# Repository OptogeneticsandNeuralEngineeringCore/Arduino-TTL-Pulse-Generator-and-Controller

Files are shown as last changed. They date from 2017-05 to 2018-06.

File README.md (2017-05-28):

# Arduino-TTL-Pulse-Generator-and-Controller

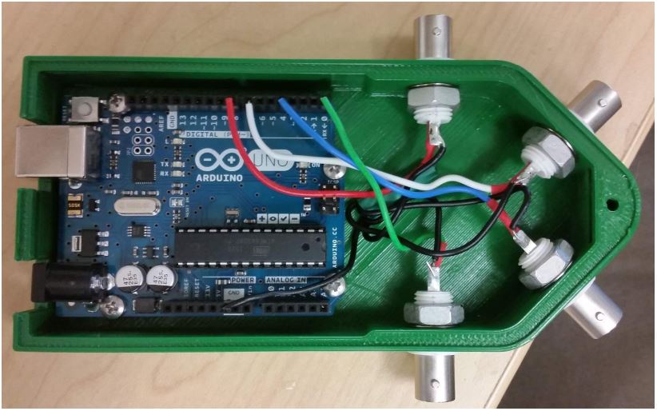
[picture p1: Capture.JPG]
Capture


Design and Control your experiments with a TTL Generator and Controller

An inexpensive Arduino controlled, four channel, simultaneous TTL pulse generator and controller with BNC connectors and optional 3D printed housing is detailed. TTL pulse modulation requires programing in the Arduino language, but 2 examples are given such **that no prior programing experience** is necessary. The first example shows how to set up four independent TTL outputs. The second example expands on this and allows for input into the generator for a closed loop system, controlled by TTL.

### Files

| File | Description | File Type  |
| --- | --- | --- |
| [Arduino Simple 4 Channel TTL Pulse Generator.pdf](https://github.com/OptogeneticsandNeuralEngineeringCore/Arduino-TTL-Pulse-Generator-and-Controller/raw/master/Arduino%20Simple%204%20Channel%20TTL%20Pulse%20Generato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) | The Main File for design and fabrication | pdf |
| Arduino simple 4 channel ttl top.ipt | Design file for enclosure top | ipt |
| Arduino simple 4 channel ttl top.stl | Printable file for enclosure top | stl |
| Arduino simple 4 channel ttl bottom.ipt | Design file for enclosure bottom | ipt |
| Arduino simple 4 channel ttl bottom.stl | Printable file for enclosure bottom | stl |
| Arduino_Simple_TTL.ino | Arduino file for TTL Generation | ino |
| Arduino_Simple_Closed_Loop.ino | Arduino file for TTL Control (TTL's triggered on input (button or IR Breakbeam) |ino |
| Screenshots of Downloading and Programing the Arduino.ppt | Help in downloading and Programing with Arduino | ppt |
| --- | --- | --- |
| --- | --- | --- |
| Arduino Simple 8 Channel MEGA TTL Pulse Generator.pdf | If more inputs/outputs are required, try the 8 channel system | .pdf |
| Arduino simple 8 channel ttl top.ipt | Design file for enclosure top | ipt |
| Arduino simple 8 channel ttl top.stl | Printable file for enclosure top | stl |
| Arduino simple 8 channel ttl bottom.ipt | Design file for enclosure bottom | ipt |
| Arduino simple 8 channel ttl bottom.stl | Printable file for enclosure bottom |stl |
| Arduino_Simple_Closed_Loop_Mega.ino | Arduino code for 8 channel system | ino |

### Introduction
Research labs often conduct experiments that require precise timing characteristics, synchronized across several signals. Pulse Width Modulation (PWM) is a digital on/off signal that carries information in the relative timing characteristics of the signal. Transistor Transistor Logic (TTL) is a form of PWM where the on state is 5 VDC and the off state is at 0 VDC. TTL is frequently employed to precisely control lab equipment such as lasers. Generation of the TTL signal often comes from expensive lab equipment and is carried through BNC cables from the generator to the equipment. The TTL signal is simple, but must be precisely controlled for correct on/off state and timing considerations. More information on TTL can be found here. Modern microcontrollers can easily accomplish the signal generation of more expensive equipment, for most applications. Arduino is a simple, inexpensive microcontroller that natively outputs TTL signals. The intent of this paper is to outline a method to fabricate an inexpensive TTL signal generator and controller. 
Arduino outputs PWM digital signals. When the Arduino is powered correctly, this signal is conveniently at 5VDC, and is therefore TTL. Although the chosen board (the Arduino Uno R3) outputs six channels, only four are employed in this design for ease. If six signals are required, it would be easy to expand on this design. If more than 6 channels are required, it may be possible to connect several Arduinos together, but there may be some delay to consider.
This document will outline the equipment, fabrication, and software required. The equipment is intended to be inexpensive. A model for an optional housing for the Arduino and four BNC connections is offered and maybe 3D printed. Fabrication of the final assembly is simple but does require the use of a soldering iron. The software is free. The Arduino programing language is similar to C+, but it is intended that no previous programing is required to generate TTL signals with this set up. Two example programs are given that are intended to be explained in such a way that signal generation can be designed simply by modifying the code in key places. One example shows how to generate four simultaneous signals, each with a unique pulse pattern that is repeated Ad infinitum. The other example shows how to use this set up to control a closed loop experiment. The examples can also be used as an introduction to coding and covers if, for, and while statements.

### ONE Core acknowledgement 
Please acknowledge the ONE Core facility in your publications. An appropriate wording would be:

"Engineering support was provided by the Optogenetics and Neural Engineering Core at the University of Colorado Anschutz Medical Campus, funded in part by the National Institute for Neurological Disorders and Stroke of the National Institutes of Health under award number P30NS048154."

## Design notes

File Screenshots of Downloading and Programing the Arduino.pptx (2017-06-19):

## Downloading the Arduino programing software and running the programs

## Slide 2

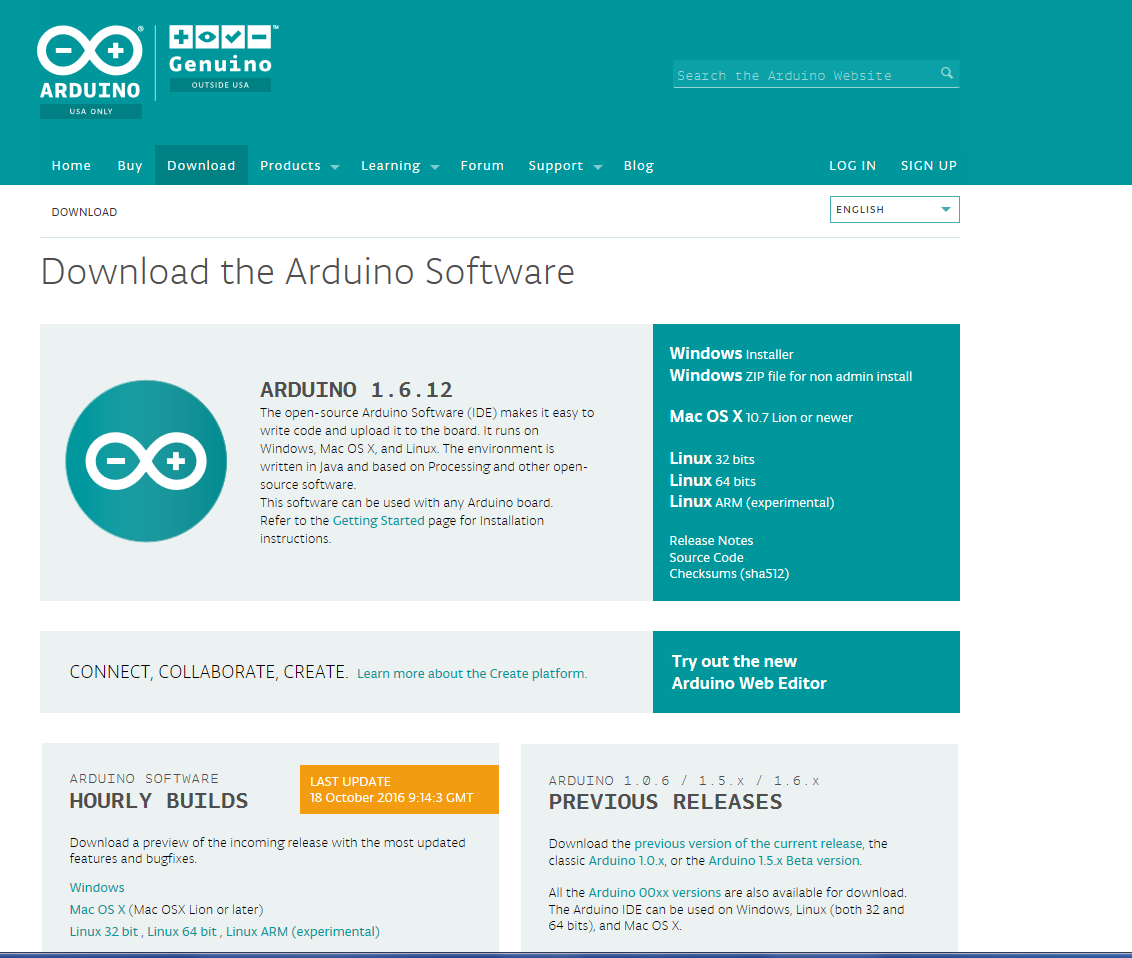
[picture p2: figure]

Installation

For windows click on windows. For mac click on mac. Follow the normal instruction for installation. Desire folder etc.

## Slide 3

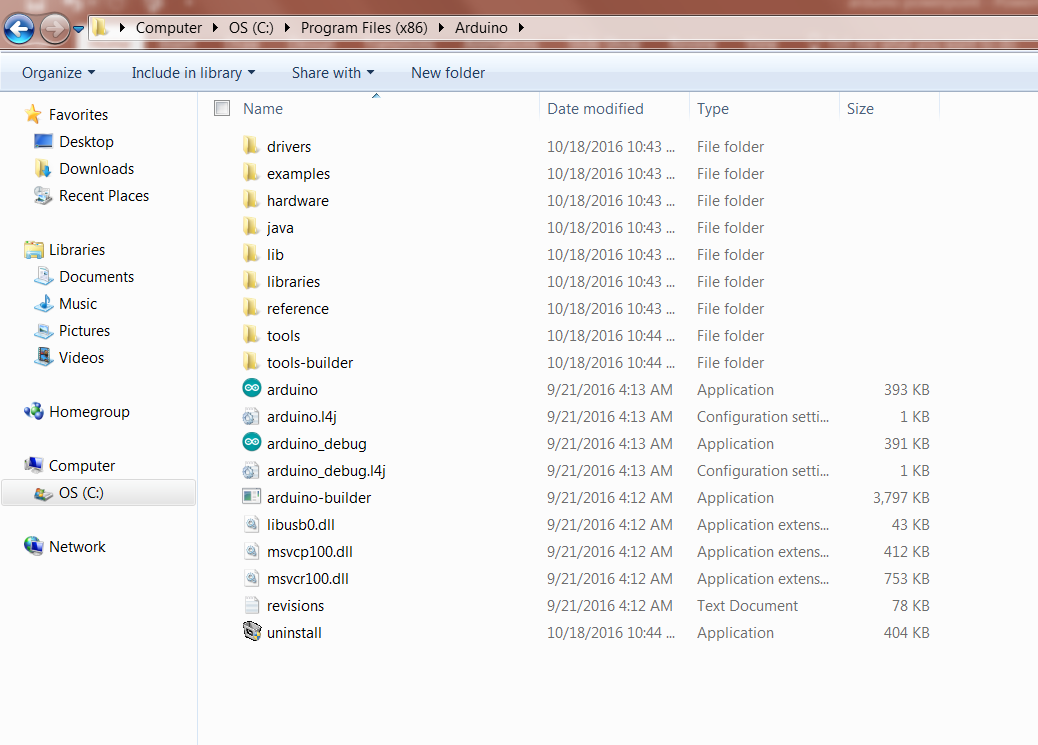
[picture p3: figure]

Go to the folder where you have installs Arduino. Click on Arduino to start the program

Installation

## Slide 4

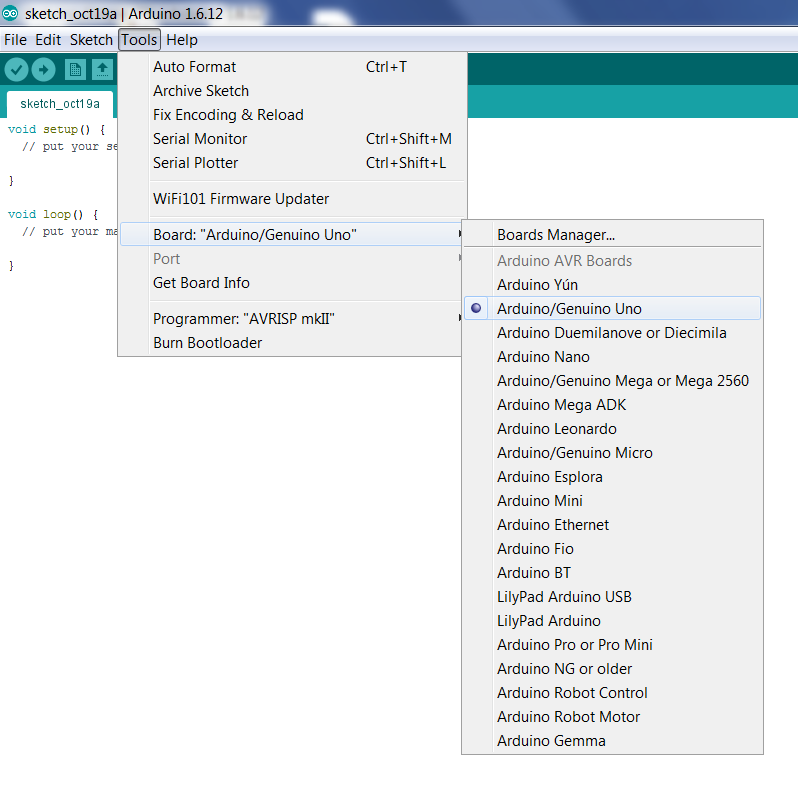
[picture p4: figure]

Connect

1. Connect the Arduino via the USB Cable.
2. In the Arduino window, select Tools > Boards > Arduino Genuiono Uno.

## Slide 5

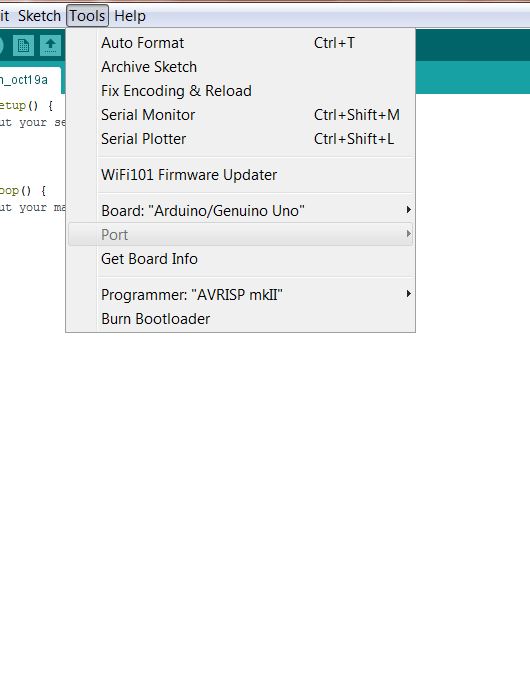
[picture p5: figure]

Connect

Then select Tools > Port > then select the board connected to the USB (typically COM4)

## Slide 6

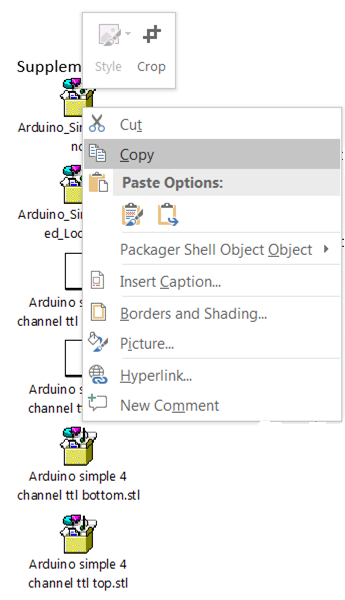
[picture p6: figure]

Obtaining files

Copy the sample files into a desire folder. Click on the file then right click and click on copy. Place the file in the desire folder. Repeat the steps for the rest of the files.

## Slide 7

Open Files

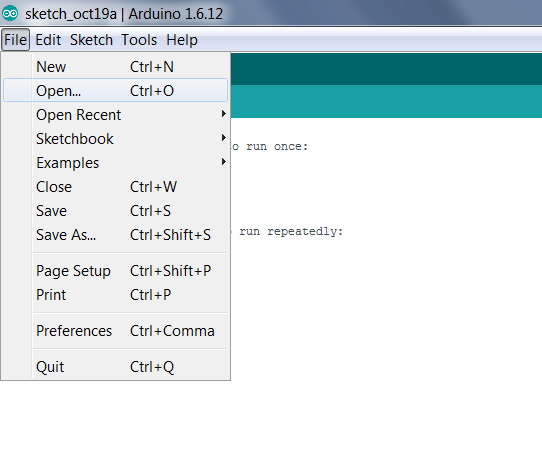
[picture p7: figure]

Open the desire program by clicking File >Arduino_Simple_Closed_loop
Or any program you want to run.

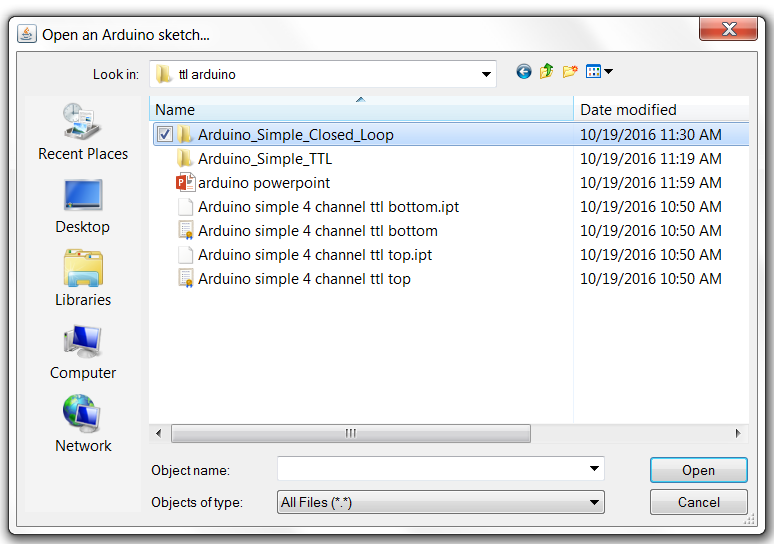
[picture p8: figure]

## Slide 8

Verify the program

Once the program is open click on the check mark

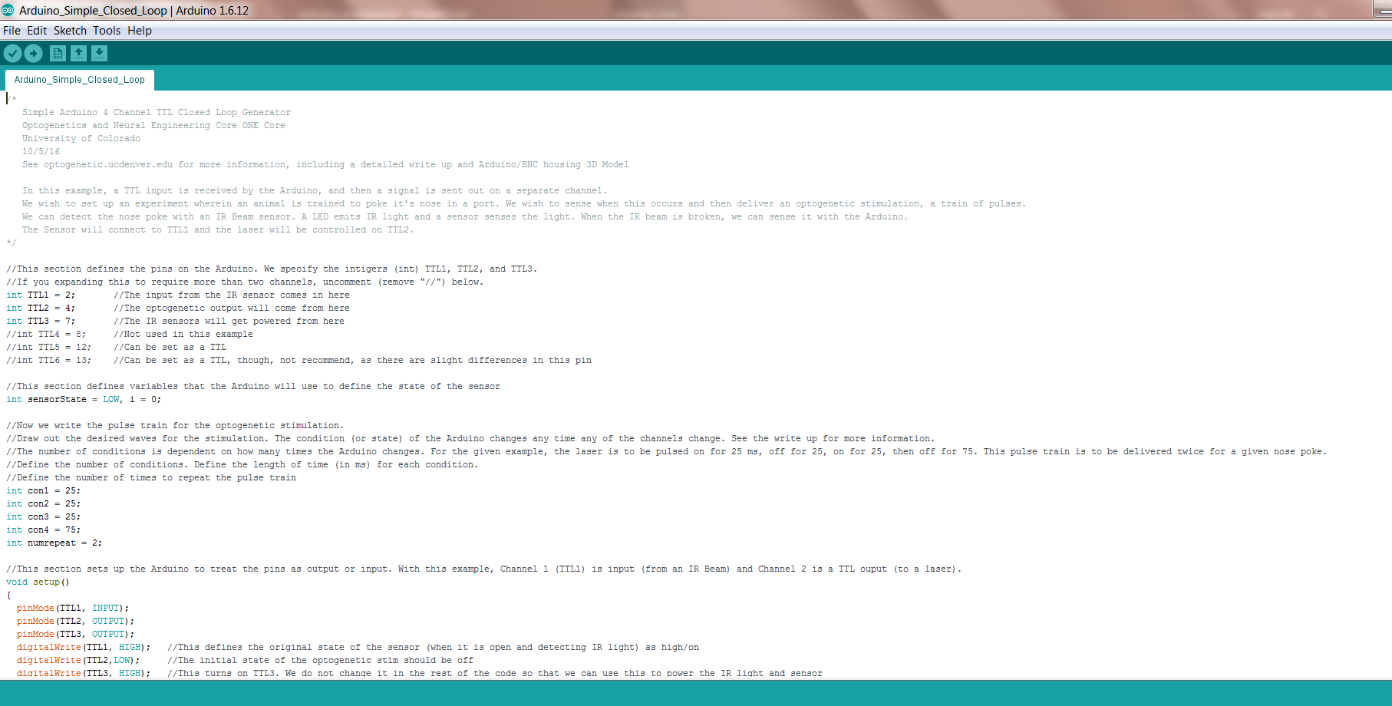
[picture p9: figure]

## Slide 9

Upload the program to Arduino

Click on the arrow to run the program

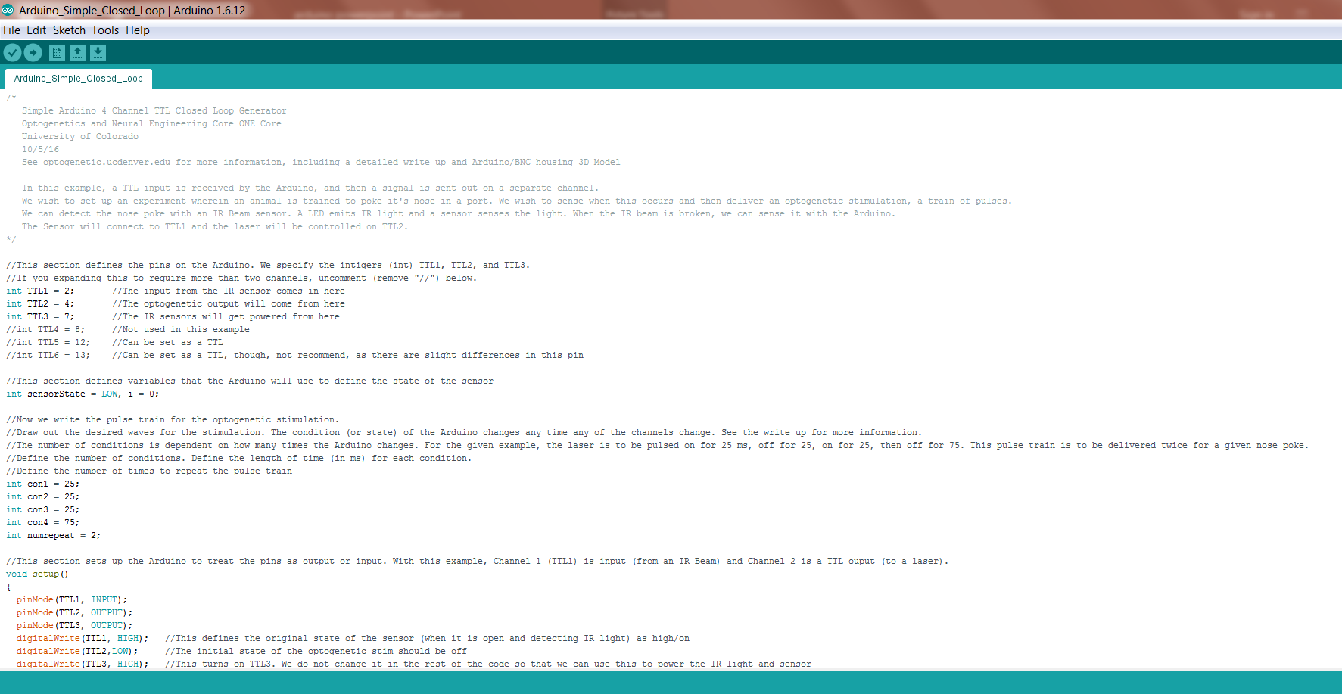
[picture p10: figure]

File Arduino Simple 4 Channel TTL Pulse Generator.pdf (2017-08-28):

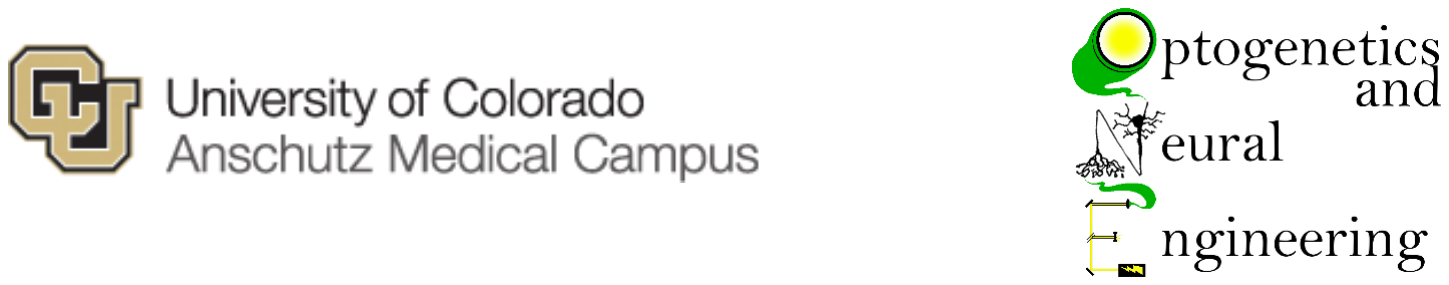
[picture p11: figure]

Arduino Simple 4 Channel TTL Pulse Generator and Controller

Developed and described by Andrew Scallon Optogenetics and Neural Engineering Core Abigail Person and Gidon Felsen, Directors Department of Physiology and Biophysics School of Medicine, University of Colorado

Introduction
Research labs often conduct experiments that require precise timing characteristics, synchronized across several signals. Pulse Width Modulation (PWM) is a digital on/off signal that carries information in the relative timing characteristics of the signal. Transistor Transistor Logic (TTL) is a form of PWM where the on state is 5 VDC and the off state is at 0 VDC. TTL is frequently employed to precisely control lab equipment such as lasers. Generation of the TTL signal often comes from expensive lab equipment and is carried through BNC cables from the generator to the equipment. The TTL signal is simple, but must be precisely controlled for correct on/off state and timing considerations. More information on TTL can be found here. (https://learn.sparkfun.com/tutorials/logic-levels) Modern microcontrollers can easily accomplish the signal generation of more expensive equipment, for most applications. Arduino is a simple, inexpensive microcontroller that natively outputs TTL signals. The intent of this paper is to outline a method to fabricate an inexpensive TTL signal generator and controller.
Arduino outputs PWM digital signals. When the Arduino is powered correctly, this signal is conveniently at 5VDC, and is therefore TTL. Although the chosen board (the Arduino Uno R3) outputs six channels, only four are employed in this design for ease. If six signals are required, it would be easy to expand on this design. If more than 6 channels are required, it may be possible to connect several Arduinos together, but there may be some delay to consider.
This document will outline the equipment, fabrication, and software required. The equipment is intended to be inexpensive. A model for an optional housing for the Arduino and four BNC connections is offered and maybe 3D printed. Fabrication of the final assembly is simple but does require the use of a soldering iron. The software is free. The Arduino programing language is similar to C+, but it is intended that no previous programing is required to generate TTL signals with this set up. Two example programs are given that are intended to be explained in such a way that signal generation can be designed simply by modifying the code in key places. One example shows how to generate four simultaneous signals, each with a unique pulse pattern that is repeated Ad infinitum. The other example shows how to use

An inexpensive Arduino controlled, four channel, simultaneous TTL pulse generator and controller with BNC connectors and optional 3D printed housing is detailed. TTL pulse modulation requires programing in the Arduino language, but 2 examples are given such that no prior programing experience is necessary. The first example shows how to set up four independent TTL outputs. The second example expands on this and allows

for input into the generator for a closed loop system, controlled by TTL.

this set up to control a closed loop experiment. The examples can also be used as an introduction to coding and covers if, for, and while statements.
All files are embedded in this document, at the bottom.

Equipment

The unit is expected to cost $165 total with all parts. It is expected that labs may have some components (like mineral oil or solder), and therefore the cost can be $108. The 3D Printed housing is highly recommended, but varies greatly in price via a supplier (see https://www.3dhubs.com/3dprint).

The 3D Printed Housing

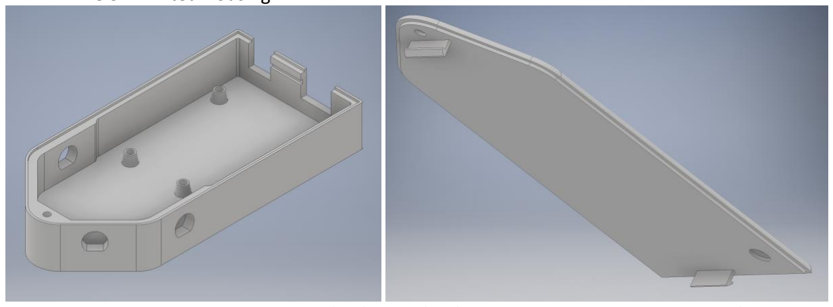
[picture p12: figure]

The 3D models are given in the deisgn file format (.ipt) as well as the industry standard for 3D printing (.stl). The parts were successfully printed with nGen at 0.25 mm layer height, 1 mm shell, and 20% infill. The top snaps to the bottom, but a M3 screw can be used as well. A button in the top allows for reset of the Arduino. The Arduino can be powered with USB or a 9 VDC power supply. The BNC connectors are secured on thick walls and are angled to minimize space while maintaining electrical isolation.

Assembly

Equipment | Supplier | PN | Cost | Unit | Comment
Arduino Uno R3 | Adafruit | 50 | 24.95 | Each
Arduino Cable | Adafruit | 900 | 2.95 | Each
Arduino Power Supply | Adafruit | 63 | 6.95 | Each
Female BNC Connectors | Mouser | 5227726-1 | 3.41 | Each | Need 4
Hookup Wire 22 AWG | Adafruit | 3175 | 27.5 | 10x25ft | Need a very small amount
Silicone Caulk | mcmaster | 63500334 | 9.51 | Tube | Any caulk will do
Heat Shrink | Amazon | 707470898884 | 10.29 | Kit | Only need very small amount
Mineral Oil | Amazon | 79567100386 | 4.59 | Bottle | Optional, need very small amount
Solder | Mouser | 601-46-502 | 3.86 | Tube | Only need very small amount
3D Printed housing | Varies | NA | 40-80 | | Optional
IR Beam | Adafruit | 195 | 21.67 | | Optional, example 2
Male BNC Connectors | Mouser | 565-4969 | 8.95 | | Optional, example 2
Total | 164.24 Total
Recommended | 108.49 Without general lab parts
Without housing | 48.49 No 3D printed housing

1. Secure the Arduino: Use the M3 screws to ‘tap’ the holes prior to placing the Arduino in the housing. Normal machine screws can tap most plastics (ABS, PLA, nGen) easily without the use of taps or self-taping screws. However, the friction may be excessive. An oil (ex: mineral oil) can be used to lessen the friction and displace the friction heat generated during taping, but be sure to clean this out if used. Place the Arduino in the housing and secure with M3 pan head screws. The screws may be metal, but must not touch more than one electrical connection on the Arduino.
2. Create Channel Wires: Cut (4) channel wires of ~8 cm length and strip off ~1 cm from all ends. Insert one end into the center pin of the BNC Connector. This center can be pinched with needle nose pliers to hold the wire until it is soldered. Solder with a generous amount of heat and solder. Isolate the center pin from ground by placing heat shrink over the solder.

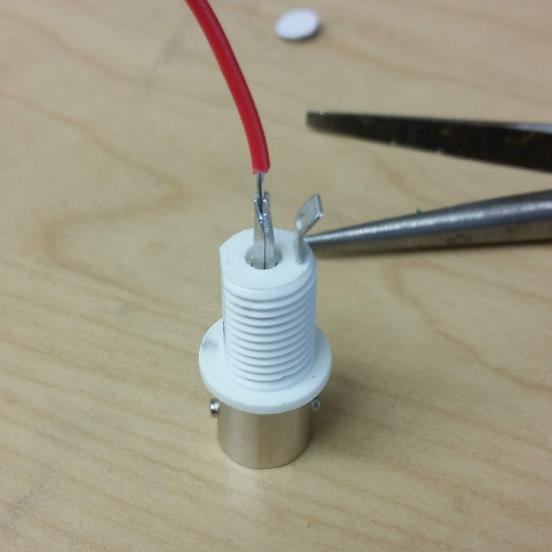
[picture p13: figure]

3. Create Ground Wire: Cut (5) ground wires of ~8 cm length and strip off ~2 cm from one end and ~1cm from the other. Twist the longer ended exposed wires together. Solder all together with a generous amount of heat and solder. Insulate this junction (recommend: dip junction in silicone and then heat shrink over this).

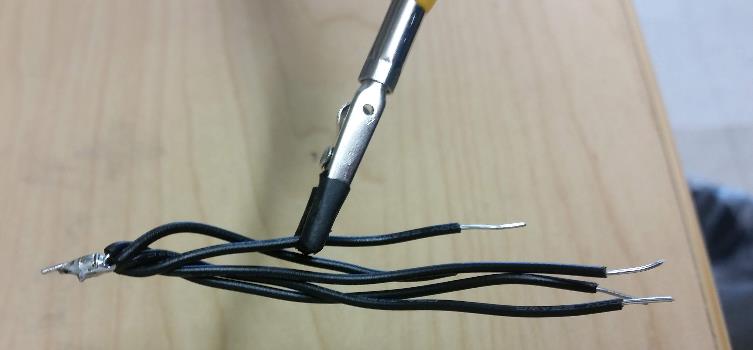
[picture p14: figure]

4. Connect Ground Wires: Twist all (5) ground wires together at one end and solder together. Connect the one lose ground wire to ground on the Arduino.
5. Place the ground wire junction in the housing below the Arduino. Place the washer and nut onto the wires before inserting the wire through the hole in the housing. Solder the ground wires to the BNC connector outside of the housing (you can insert the wire through the hole in the BNC Connector, fold over, and pinch with pliers for ease). Then insert the channel wire through the hold in the housing and then through the washer and nut. Secure the BNC Connector to the housing by tightening the nut.

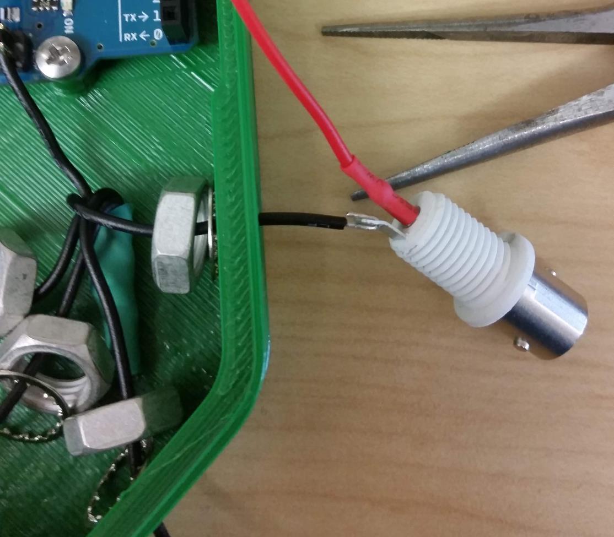
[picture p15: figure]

6. Connect Channel Wires: Connect each lose wire to the appropriate pin on the Arduino. Channel 1 to pin 2; Channel 2 to pin 4; Channel 3 to pin 7; Channel 4 to pin 8.

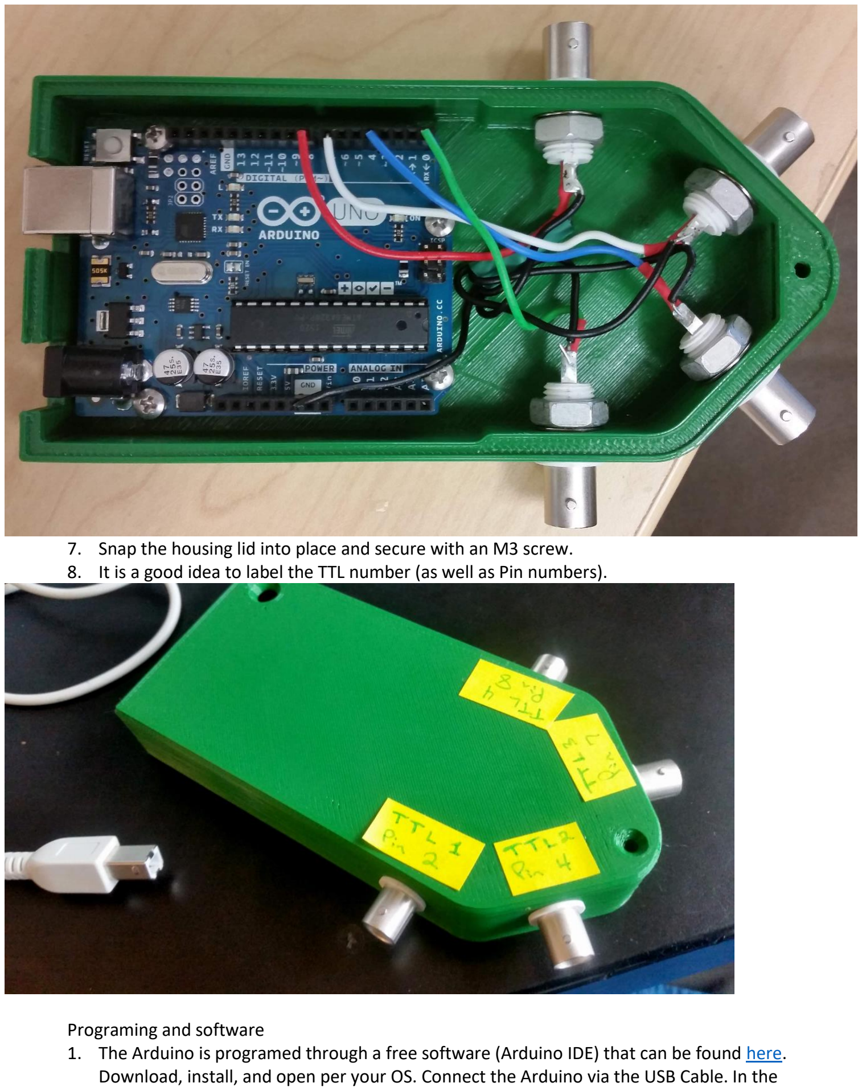
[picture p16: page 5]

7. Snap the housing lid into place and secure with an M3 screw.
8. It is a good idea to label the TTL number (as well as Pin numbers).

Programing and software
1. The Arduino is programed through a free software (Arduino IDE) that can be found here. (https://www.arduino.cc/en/Main/Software) Download, install, and open per your OS. Connect the Arduino via the USB Cable. In the

Arduino IDE, select Tools > Boards > Arduino Genuiono Uno. Then select Tools > Port > then select the board connected to the USB (typically COM4)
2. Open the desired file in the Arduino IDE via File > Open. Upload this to the Arduino by selecting the Upload button (right arrow button in the top left). A progress bar is indicated at the bottom right. Wait for the Done Uploading to appear. The Arduino will automatically restart and will immediately start outputting the TTL pulses.

Example 1: Simple 4 Channel TTL Pulse Generator
This example will describe how to generate four simultaneous signals, each with a unique pulse pattern that is repeated Ad infinitum. If fewer than 4 channels are required, you can simply leave the other channels as off (LOW), or they may be commented out (place “//” in the beginning of a line). Hardware set up: Connect all four BNC’s to a four probe Oscilloscope. All channels on the oscilloscope should be set to 5 V divisions, 100 ms scales, and trigger off of channel 1.
To start, trace out the desired pulsing on paper, with each trace on the same timeline. In this example, the first channel will output a 50 ms pulse, then remain off for 50 ms. The second channel will pulse on and off for 25 ms each. The third channel is to be off only during the second on pulse of channel 2. The forth channel is to remain off the entire time. This would look like:

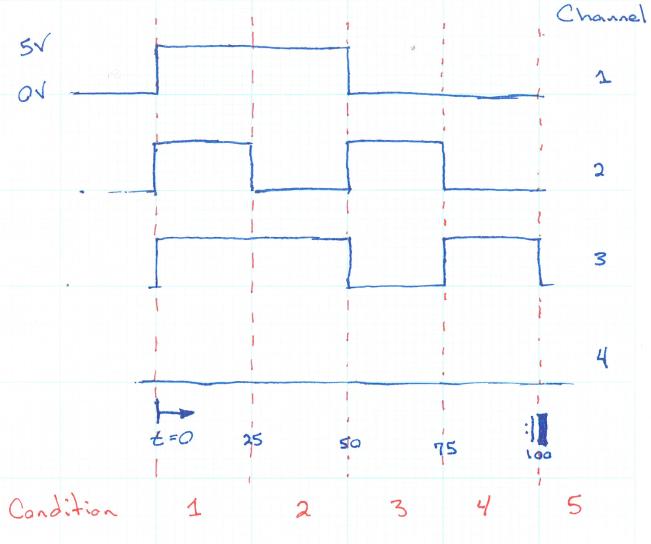
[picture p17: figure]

The Arduino will act like a person at a light switch, turning on or off the channels when directed to do so, and simply waiting in-between. Any time any of the switches changes, the ‘condition’ of the Arduino changes. We can therefore define the condition of the Arduino across the entire pulse train. For the given example, we can define 4 or 5 conditions (more on this later). Each condition in this chosen example lasts 25 ms, but the durations of conditions can be independent. Any time any of the TTL’s change, draw a vertical line and label it as a new condition. We can then define the state of each TTL channel for a condition. We can also define the time (t) for the duration of each condition.
Open the Arduino_Simple_TTL.ino file with the Arduino IDE. It is broken into sections. The first section is an introduction. The next section defines what pins we will be connecting to on the Arduino. We then run a set up to tell the Arduino that these are all output digital pins. These first sections will typically remain unchanged. The next section begins to deal with the desired pulses. Here we define the duration of each condition. The given example has four conditions last 25 ms. You could also consider a fifth condition of zero time, but wherein all pulses are turned off (more on this later).
The final section is the heart of the code. This is the looping code that the Arduino will loop/repeat through. We label each condition, tell the Arduino how to set the switch of each channel, and then tell the Arduino how long to wait in that condition. Uploading this to the Arduino will output the following to an oscilloscope:

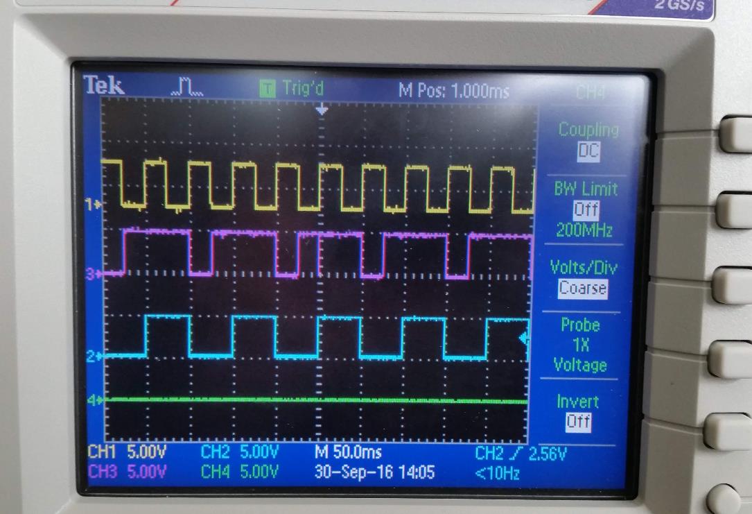
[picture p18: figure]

(Note that channels 2 and 3, although appropriately labeled by color, are swapped in horizontal placement in the picture.) The outputs are well synced, accurately timed, and repeat continuously. However, looking at channel 3, you will note that most waves appear uniform, but the middle pulse has a divot in the middle. If one were to zoom in, you would see that all pulses on this channel has this feature. This is because, although we chose condition 5 to be of zero ms, we still told the Arduino to switch off all pulses, including channel 3. The Arduino turns channel 3 off and then on between the pulse trains. It is therefore recommended that the state between pulse trains not be considered as a condition, but you must at least consider how the pulse train end matches the beginning.

Timing considerations

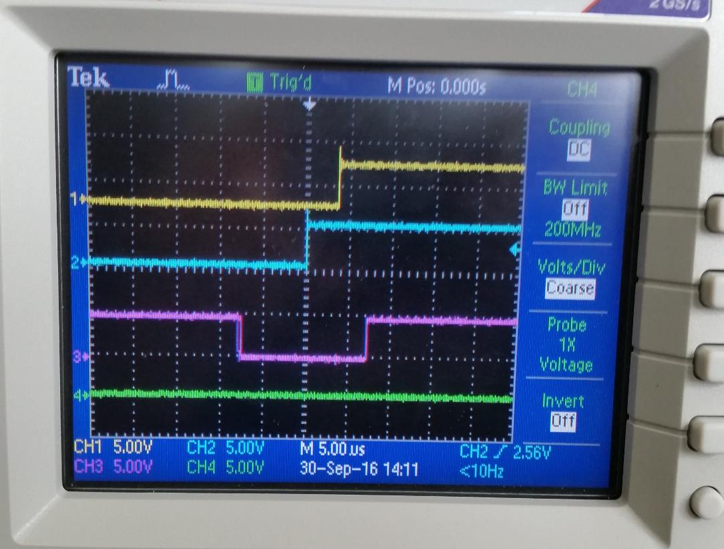
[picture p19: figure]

When you zoom in on the oscilloscope trace, you will note that there is a delay in when the channels are turned on; they are not turned on all at once. This is a limit of the Arduino clock speed. For the Arduino Uno. There will be at minimum a 4 us delay between turning on two channels. If 6 channels are used, this could result in a delay of 24 us between channels. For most biological applications, this is not an issue, but it is strongly recommended that this be considered for any experiment. Note that the Arduino can be over-clocked (sped up at the risk of damaging parts). The Arduino Duo has a clock speed 5.25 faster, and would presumably decrease this delay by a factor of 5.25. The order of which channels are turned on is also tunable, but all this is beyond the scope of this paper.

Example 2: Arduino Simple Closed Loop
This example will show how to use the Arduino to deliver a TTL pulse only after some TTL input is received. As an example, suppose we wish to set up an experiment wherein an animal is trained to poke its nose in a port. We wish to sense when this occurs and then deliver an optogenetic stimulation; a train of pulses. We can detect the nose poke with a very inexpensive IR Beam sensor. In this sensor system, an LED emits IR light (not detectable by human nor mouse vision) and a sensor senses the light. When the IR beam is broken by the mouse nose, we can detect it and deliver this information to the Arduino via a TTL signal. We can then use another channel to output a TTL signal to a laser to optically stimulate a brain region of interest. A third channel will be set to continuously on to power the IR light and IR sensor.
Hardware setup: Connect TTL2 (the optogenetic output) to an Oscilloscope set to 5 V divisions, 100 ms. The IR LED and sensor can be powered through the same pins in parallel. It may be handy to solder the like colors together (that is, solder the IR LED red wire to the IR sensor red wire). Connect these wires to a male BNC on TTL3 (power for the LED and sensor). Finally, connect the white wire on the IR sensor to the positive terminal of TTL1 (there is no ground for this sensor; the Arduino will use its own ground). The IR LED and sensor can be kept aligned to each other with some rod (Allen wrench pictured).

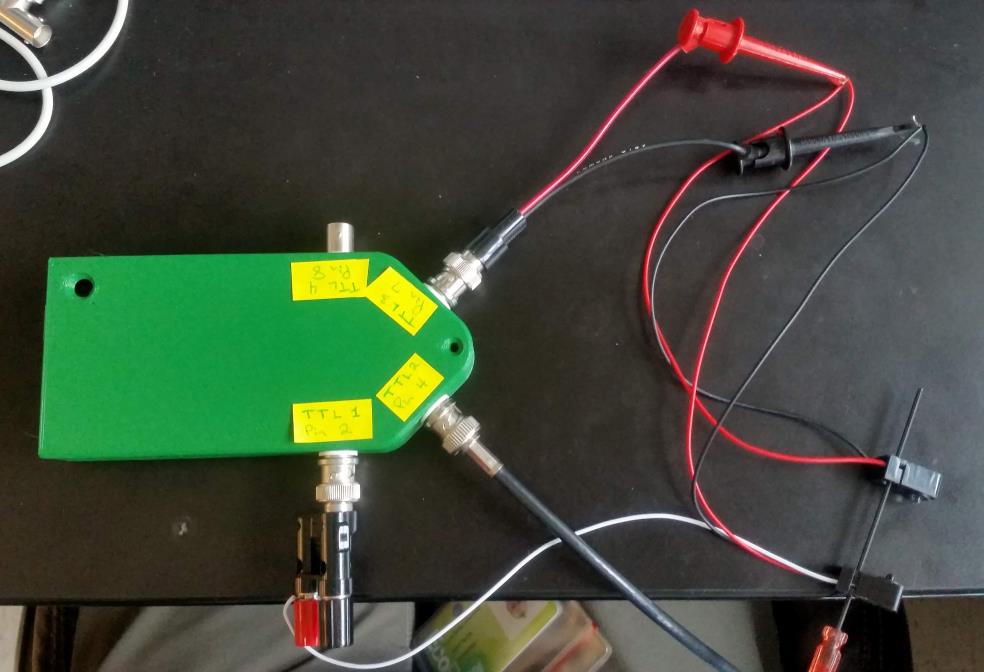
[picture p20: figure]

Again we should begin by defining and drawing the TTL pulse train we would like to use. For this example, we would like to deliver two evenly spaced pulses with a long delay at the end. We want this pulse train delivered twice. It is important to note that this pulse train be delivered only twice per nose poke.

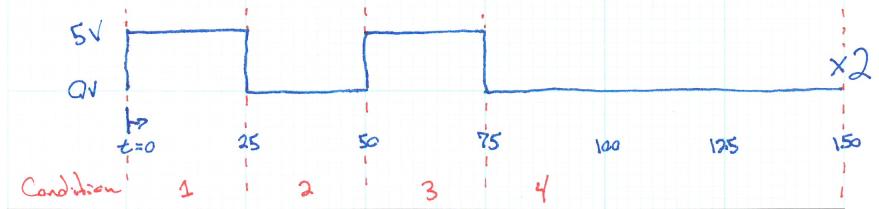
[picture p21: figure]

Open the Simple_Closed_Loop.ino file in the Arduino IDE. Again there is an introduction. The next section defines the pin output on the Arduino. Although we have 4 pins physically mounted, we are only using 1-3, so the rest are commented out (“//”). We next define variables that Arduino will use to monitor the state of the system. These are internal numbers that Arduino uses. The next section, the condition section, where we define the timing characteristics of the optogenetic stimulation. This is the waveform drawn above (see Example 1 for more information).
The next section tells the Arduino to treat the pins as either output or input. We assume that the initial state of the sensor will be that the beam is on and detected. On is high. We therefore set the initial state of the sensor as high. We next set the initial state of the optogenetic TTL2 to low, as we assume the optogenetic stimulation should start as off. Finally, we set TTL3 as high. The remaining code does not change this value, so as long as the Arduino receives power, this channel will remain at 5 VDC. We can use this to power low current components, such as the IR LED and sensor. Components that draw more than 40 mA (or shorting this circuit) can damage the Arduino.
The next the section is the code that Arduino will continuously loop through. It starts by reading the state of the sensor. It then checks if state of the sensor is low (IR Beam broken). This ‘if’ command can be read as: if the sensor state is low, then execute the indented code, if the sensor state is not low, do not execute the indented code, move to the ‘else’ command. The else section gives opportunity to have the Arduino do something while the animal is not in the nose poke.
If the sensor is low (the beam is broken), the ‘if’ command is true and the Arduino will look at the indented code. The ‘for’ code can be read as: for as long as variable (i), originally set to zero, is less than variable numrepeat (here 2), execute the further indented code, but then at the end add one to the variable (i++). So, for the first time Arduino sees this code, i=0, so it executes the further indented code, adds one to i, and starts again. This time, i=1, which is less than 2, so it again executes the further indented code and adds one to 1. Now i=2, which is not less than 2, so it does not execute the condition code.
The further indented code, or ‘condition’ code (which outputs the pulse train) can be understood by working through Example 1: Simple 4 Channel TTL Pulse Generator.
We then say that if we have run through the optogenetic stimulation numrepeat times, reset the sensor to high (this was the same as what was done in the initialization).
If the code were to end here, the Arduino would start the loop over. That is, immediately after delivering the optogenetic stimulation, it would start over and read the sensor. The stimulation delivered is very short (2*150 = 300 ms) and it is probable that the mouse could still be in the nose poke. The sensor would be read as low, and another optogenetic stimulation would be delivered. But we said in the beginning we only want one optogenetic stimulation per nose poke. We should therefore wait until the mouse leaves the nose poke. A while command can achieve this. The while statement can be read as: while the sensor state is low (off), delay 500 ms (.5 seconds), read the sensor state again, repeat.

Supplementary Files
Files may be opened directly from this Word Document, or maybe copied into a folder of your choice.

Screenshots of
Downloading and Programing the Arduino.pptx
Screenshots of installing Arduino Software and uploading programs to the Arduino.

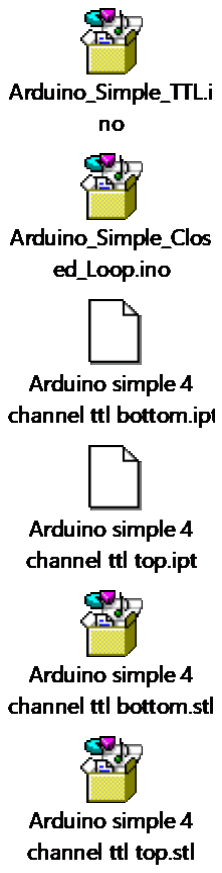
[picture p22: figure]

The Arduino code for Example 1: Simple 4 Channel TTL Pulse Generator

The Arduino code for Example 2: Arduino Simple Closed Loop

The Design File (for modification) of the 3D housing bottom

The Design File (for modification) of the 3D housing top

The 3D Model for printing the housing bottom

The 3D Model for printing the housing top

Please acknowledge our facility in your publications. An appropriate wording would be:

"Engineering support was provided by the Optogenetics and Neural Engineering Core at the University of Colorado Anschutz Medical Campus, funded in part by the National Institute for Neurological Disorders and Stroke of the National Institutes of Health under award number P30NS048154."

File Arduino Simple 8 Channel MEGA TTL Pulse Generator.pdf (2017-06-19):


Arduino Simple 8 Channel MEGA TTL Pulse Generator and Controller

Developed and described by Andrew Scallon Optogenetics and Neural Engineering Core Abigail Person and Gidon Felsen, Directors Department of Physiology and Biophysics School of Medicine, University of Colorado

Introduction
This document expands on previous work done with an Arduino to generate TTL pulses (see optogenetic.ucdenver.edu for more information). The previous documents showed how to fabricate an inexpensive TTL pulse generator and controller including the equipment necessary, assembly methods, software, and timing characteristics. Two examples were given to highlight how to obtain the required TTL pulse with little to no previous programming experience. The first example shows 4 independent TTL pulses delivered ad infimum. The second example demonstrated how monitor an area with an IR break beam sensor and output a TTL pulse for laser stimulation. This example expands on these for more BNC TTL inputs/outputs. See previous examples for more information on assembly and programing. All files are embedded in this document, at the bottom.
This example outlines how to set up the system for monitoring 4 arms of a behavioral maze. When the animal is detected in Arms 1 or 3, a TTL is output appropriate for ChR2 activation. When in Arm 2, there is output for Jaws activation. When in Arm 4, a reward port is opened for 4 seconds.

Equipment
All equipment used is the same as previous examples except that the Arduino has been upgraded to the Arduino Mega (Adafruit PN 191, $45.95). The Arduino Mega inputs/outputs TTL (PWM) on pins 2-13 and 44-46.

The 3D Printed Housing
The 3D Printed Housing has been expanded to accommodate the larger Arduino Mega. It also allows for two additional protrusions for the additional BNC connectors while minimizing print material. The 3D models are given in the deisgn file format (.ipt) as well as the industry standard for 3D printing (.stl). The parts were successfully printed with nGen at 0.25 mm layer height, 1 mm shell, and 20% infill,

A previous Arduino controlled TTL pulse generator and controller has been discussed. This paper expands on this example to allow for 8 independently controlled TTL signals.

### Updated housing is provided to allow for Arduino Mega use and 8 BNC connectors. An example is given for closed loop optogenetics that allows for 4 arm maze monitoring

with IR Break Beams and control of ChR2 activation, Jaws activation, and a reward port.

no supports needed. The top snaps to the bottom, but a M3 screw can be used as well. Two holes are put into the top as it was noted that the reset button on the Arduino Mega can come in two locations.

Assembly

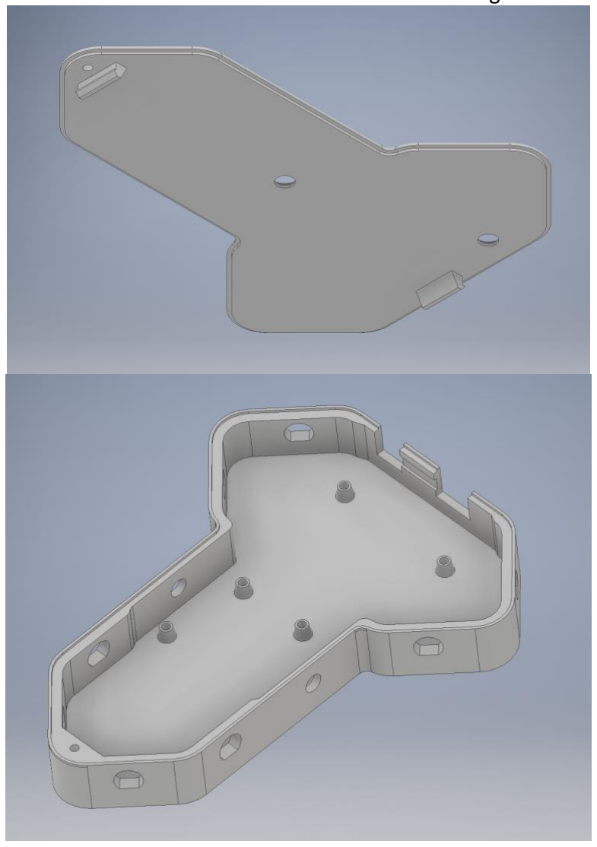
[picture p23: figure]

1. The assembly process is similar to the previous examples. Grounds can be soldered together to pins of nearby BNCs. Grounds can then go to available spots on the Arduino Mega.
2. In the picture below, the bottom right BNC was chosen as TTL1. It therefore routes to pin 2 on the Arduino Mega. The remaining pins are chosen to increase from there in counter-clockwise fashion, and therefore go from pins 3 to 9. It is recommended to label the TTL’s directly on the housing.

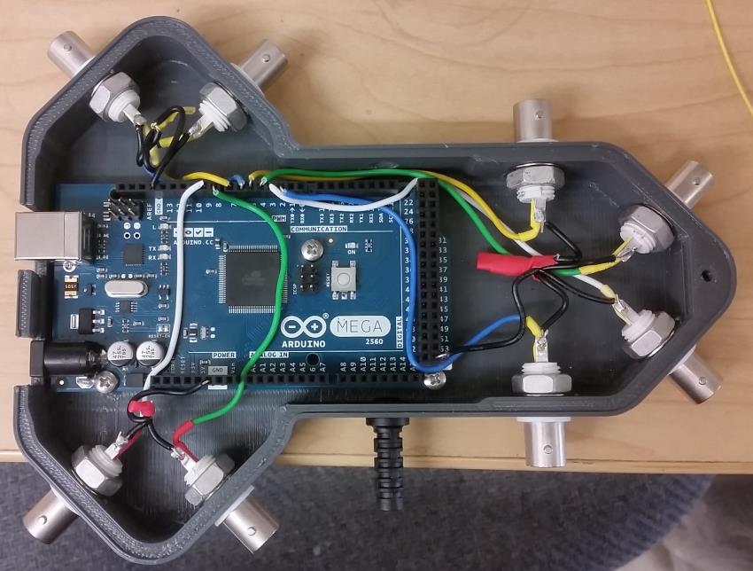
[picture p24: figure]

Example 3: Arduino Mega 8 TTL Pulse controller
To start, trace out the desired pulsing on paper, with each trace on the same timeline. In this example, from literature, we note that appropriate stimulation of CHR2 is 10 ms pulses, repeated 20 times at 20 Hz. Similarly, to previous examples, it is recommended that this be drawn out. Note that Arduino works in milliseconds, so let’s work in that. First draw out a 10 ms on pulse. Then note that 20 Hz is (=(1/20)*1000) 50 ms. So the pulse must be off (=50-10) 40 ms. This is repeated 20 times. Appropriate stimulation of Jaws is 1 second pulse, repeated once at .1 Hz. So draw an on pulse for (=1*1000) 1000 ms. This is repeated at .1 Hz, or (=.1/1000) 10,000 ms. The off pulse is therefore (=10,000-1000) 9000 ms.

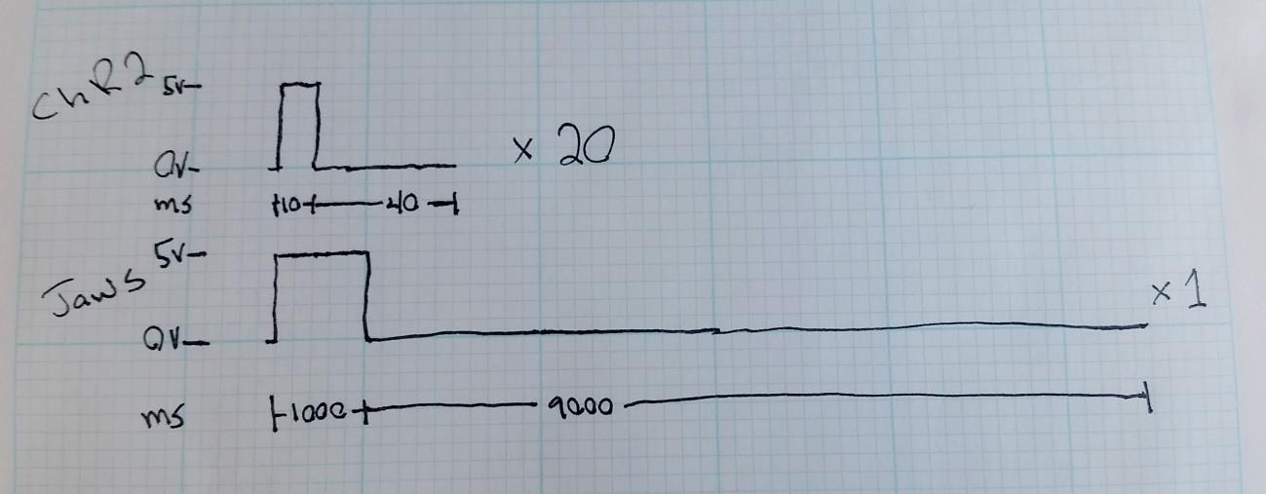
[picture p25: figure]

Again, it is recommended that the previous examples be understood before working through this example. Open the Arduino_Simple_Closed_Loop_Mega.ino file with the Arduino IDE. It is broken into sections. The first section is an introduction. The next section defines what pins we will be connecting to on the Arduino. The PWM (TTL) pins on the Arduino Mega run from 2-13 and 44-46. We will use 8 pins to control the BNC’s. We will therefore use pins 2-9. We then run a set the initial state of the sensor variable (sensorState). The Arduino will look at a sensor and determine the state (IR beam broken or not) and store the value here. These first sections will typically remain unchanged.
The next section begins to deal with the desired pulses. Here we define the duration of each condition. And the number of times the waveform is repeated.
The next section is the defining of a placeholder variable used internally by the Arduino.
The next section defines the input vs output of the TTL pulses. We have chosen the arms of the maze (1 through 4) to be represented by TTL pulses 1 through 4. TTL 5 will power the IR Beam and Sensors. TTL 6 will be the output for ChR2, TTL 7 will output for Jaws, and TTL 8 will be the reward port. We then define the initial states of the pins. All sensors should be set to high initially. We set TTL5 high and do not change this with the rest of the code. This will deliver the power to the sensors and IR Beams. The initial state of the lasers is off. The initial state of the reward port was chosen as high (reward port closed).
The final section is the heart of the code. This is the looping code that the Arduino will loop/repeat through. This code is the same as what was discussed with Example 2, repeated 4 times (once for each IR Beam). The Arduino reads each of the sensor TTLs. If the beam is broken, it goes through the indented code. For example, it first reads TTL1. If TTL1 is low (IR Beam is broken), it executes the indented code. That is, for TTL1, it cycles through for the number of times the waveform is repeated (for ChR2 we chose 20), writing the TTL high (laser on), waiting for the number of ms the waveform is on (we chose 10), writing the TTL low (laser off), waiting the number of ms the waveform is off (we chose 40), then repeating until we reach the number of times we said to cycle through (we chose 20). When done, reset to the sensor to the high state (as was done initially). We then reread the state of the sensor to ensure that the stimulus is delivered only once while the animal breaks the IR beam. We wait 500 ms (.5 seconds), and then reread the sensor. This repeats while the sensor is still broken. The Arduino then moves on to the next IR sensor.

Supplementary Files
Files may be opened directly from this Word Document, or maybe copied into a folder of your choice.

Screenshots of
Downloading and Programing the Arduino.pptx
Screenshots of installing Arduino Software and uploading programs to the Arduino.


The Arduino code for Example 3: Simple 4 Channel TTL Pulse Generator

The Design File (for modification) of the 3D housing bottom

The Design File (for modification) of the 3D housing top

The 3D Model for printing the housing bottom

The 3D Model for printing the housing top

Please acknowledge our facility in your publications. An appropriate wording would be:

"Engineering support was provided by the Optogenetics and Neural Engineering Core at the University of Colorado Anschutz Medical Campus, funded in part by the National Institute for Neurological Disorders and Stroke of the National Institutes of Health under award number P30NS048154."

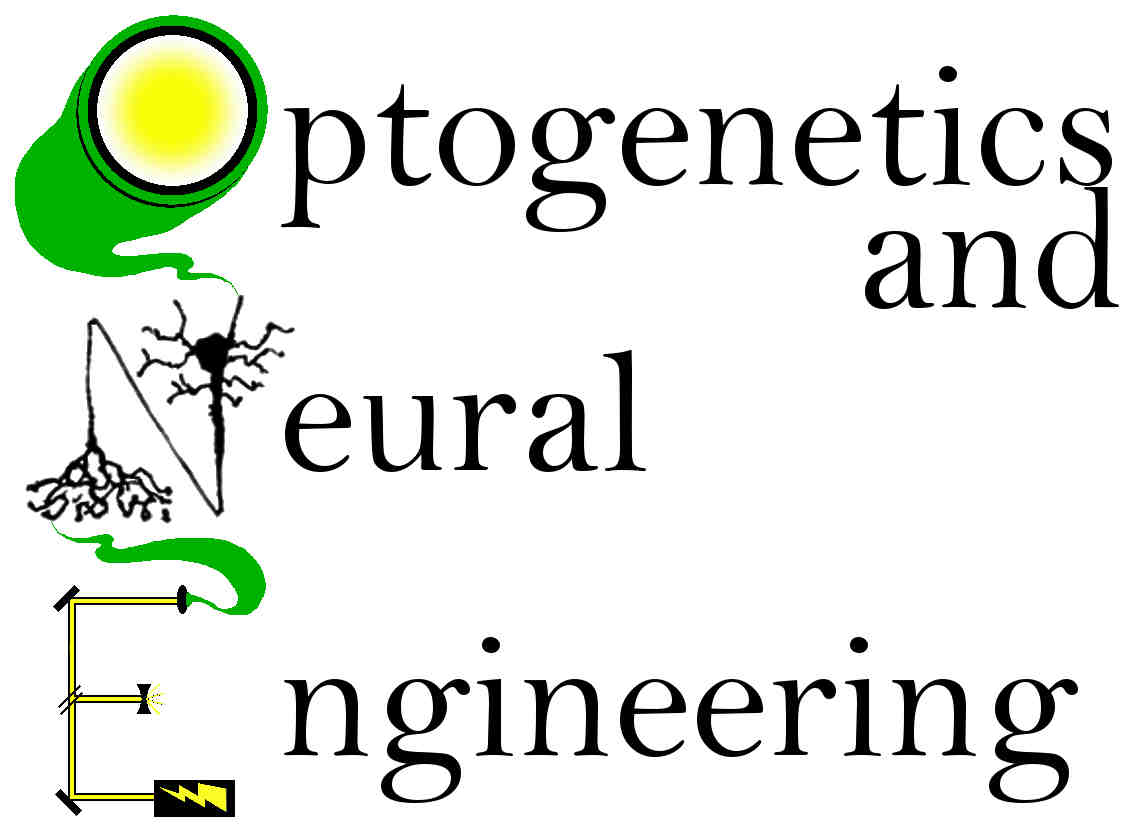
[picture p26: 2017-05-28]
Final Cut Color Small.jpeg

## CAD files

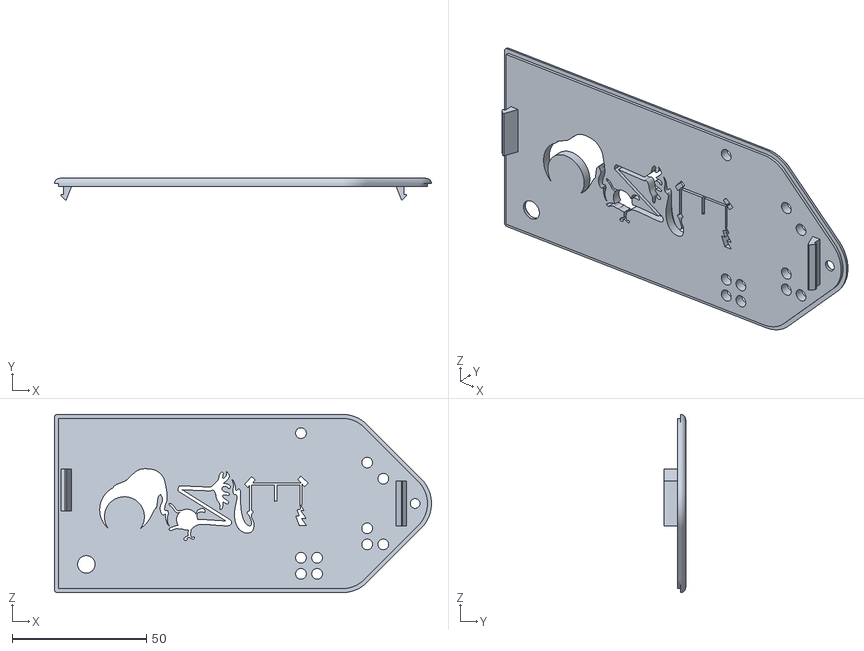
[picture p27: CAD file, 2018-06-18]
Arduino simple 4 channel ttl top.stl
140.2 x 8.00 x 66.3

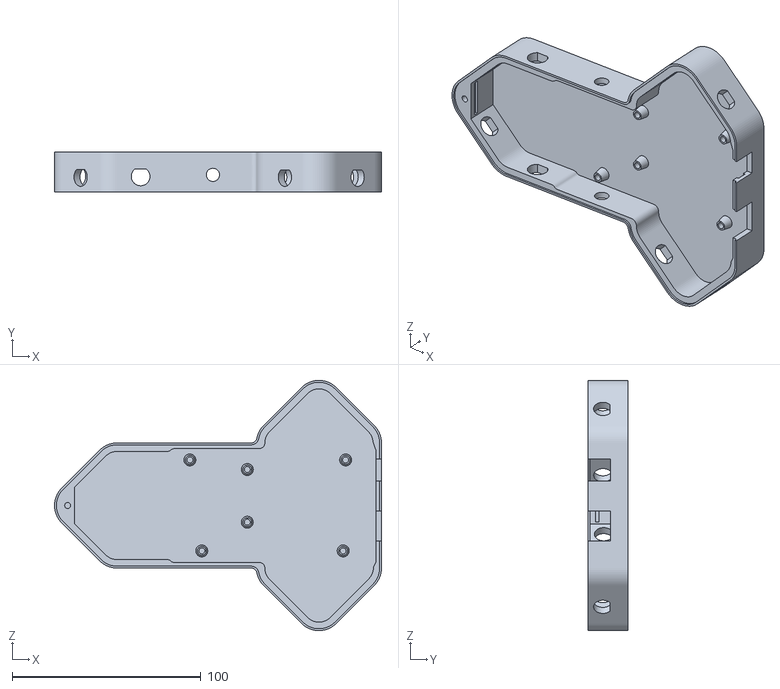
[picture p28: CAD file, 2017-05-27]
Arduino simple 8 channel ttl bottom Mega.stl
173.2 x 21.3 x 132.6

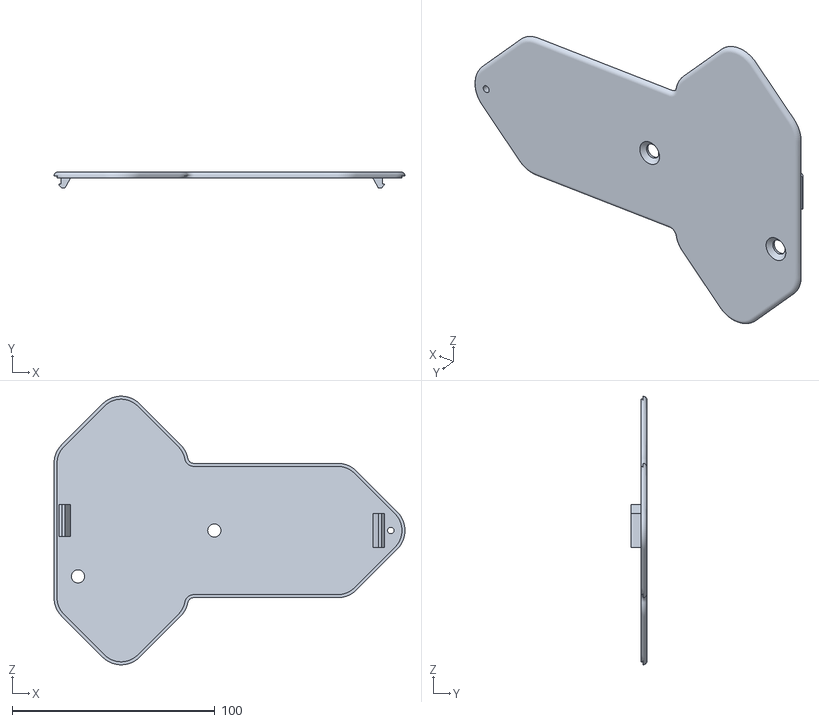
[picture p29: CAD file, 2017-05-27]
Arduino simple 8 channel ttl top Mega.stl
173.2 x 8.00 x 132.6

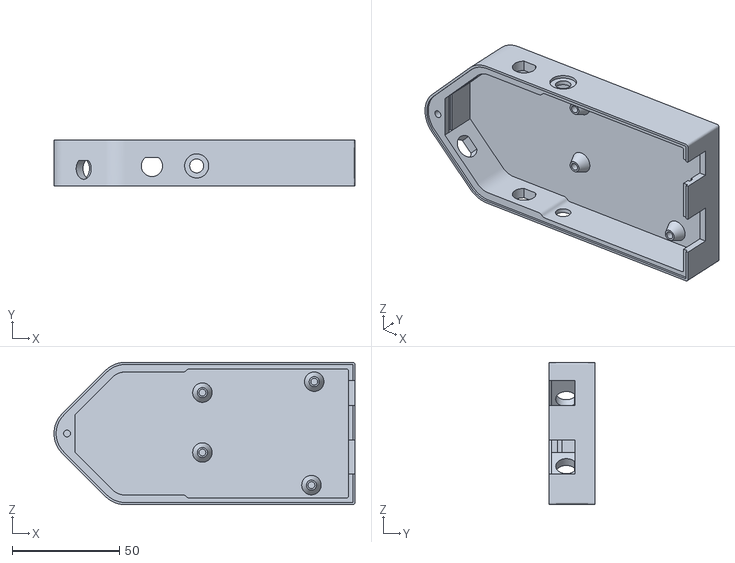
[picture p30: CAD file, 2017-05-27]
Arduino simple 4 channel ttl bottom.stl
140.2 x 21.3 x 66.3

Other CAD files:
Arduino simple 4 channel ttl bottom.ipt
Arduino simple 4 channel ttl top.ipt
Arduino simple 8 channel ttl bottom Mega.ipt
Arduino simple 8 channel ttl top Mega.ipt

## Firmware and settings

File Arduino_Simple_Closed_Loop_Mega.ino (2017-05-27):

/*
   Simple Arduino 4 Channel TTL Closed Loop Generator
   Optogenetics and Neural Engineering Core ONE Core
   University of Colorado
   10/5/16
   See optogenetic.ucdenver.edu for more information, including a detailed write up and Arduino/BNC housing 3D Model
   
   In this example, an Arduino Mega is used to sense a animal behavior in a four arm maze. Four IR beams detect presence of the animal. Based on which arm the animal is detected in, the Arduino can output TTL 
   pulses appropriate for lasers and reward. We assume only one animal per experiment and only one sensor can be activated at a time. When the animal is in Arms 1 or 3, we wish to stimulate ontogenetically
   a laser for CHR2. When the animal is in Arm 2, we wish to stimulate a laser appropriate for Jaws. When the animal is in Arm 4 we wish to open a reward port.
   
   TTL 1-4: Arduino inputs: sensors in maze arms 1-4
   TTL 5: Arduino output: continuous power for the IR Beams
   TTL 6: Arduino output: TTL signal to trigger laser for CHR2 activation
   TTL 7: Arduino output: TTL signal to trigger laser for Jaws activation

   Arduino MEGA inputs/outputs TTL (PWM) on pins 2-13 and 44-46.

   Appropriate stimulation of CHR2 is 10 ms pulses, repeated 20 times at 20 Hz.

   Appropriate stimulation of Jaws is 1 second pulse, repeated once at .1 Hz.

   The reward port is closed when the TTL pulse is set to high and opens when it goes low. The animal has 4 seconds to retrieve the reward after the beam is broken.
*/

//This section defines the pins on the Arduino. Simply define all inputs/outputs
int TTL1 = 2;       //We set this pin (the first PWM on Mega) to sense the nose poke of the first arm
int TTL2 = 3;       //We set this pin to sense the nose poke of the second arm
int TTL3 = 4;       //We set this pin to sense the nose poke of the third arm
int TTL4 = 5;       //We set this pin to sense the nose poke of the fourth arm
int TTL5 = 6;       //Power for the IR Beams so then can send IR Light

int TTL6 = 7;       //Signal to control the LED or Laser for CHR2 activation
int TTL7 = 8;       //Signal to control the LED or Laser for Jaws activation
int TTL8 = 9;       //Signal to control reward port 

//This section defines variables that the Arduino will use to define the state of the sensors. There are 4 sensors, so we need four sensor states
int sensorState1 = LOW;
int sensorState2 = LOW;
int sensorState3 = LOW;
int sensorState4 = LOW;

//Now we write the pulse train for the outputs of the system: two optogenetic stimulation and one reward port. Because we assumed that the the animal can only break one beam at a time, the
  //outputs are independent. Therefore, the conditions of each output are independent. 
//Draw out the desired waves for each output. The condition (or state) of the Arduino changes any time the channels change. See the write up for more information.
//Define the number of conditions. Define the length of time (in ms) for each condition.
//Define the number of times to repeat the pulse train
int ChR2con1 = 10;
int ChR2con2 = 40;
int ChR2numrepeat = 20;

int Jawscon1 = 1000;
int Jawscon2 = 10000-Jawscon1;
int Jawsnumrepeat =1;

int Rewardcon1 = 4000;
int Rewardnumrepeat = 1;

//Placeholder for Arduino to count with
int i = 0;

//This section sets up the Arduino to treat the pins as output or input and the initial states.
void setup() 
{
  pinMode(TTL1, INPUT);       //Arm1
  pinMode(TTL2, INPUT);       //Arm2
  pinMode(TTL3, INPUT);       //Arm3
  pinMode(TTL4, INPUT);       //Arm4
  pinMode(TTL5, OUTPUT);      //Sensor power
  pinMode(TTL6, OUTPUT);      //Laser1
  pinMode(TTL7, OUTPUT);      //Laser2
  pinMode(TTL8, OUTPUT);      //Reward
  
  digitalWrite(TTL1, HIGH);   //This defines the original state of the sensor (when it is open and detecting IR light) as high/on
  digitalWrite(TTL2, HIGH);   //This defines the original state of the sensor (when it is open and detecting IR light) as high/on
  digitalWrite(TTL3, HIGH);   //This defines the original state of the sensor (when it is open and detecting IR light) as high/on
  digitalWrite(TTL4, HIGH);   //This defines the original state of the sensor (when it is open and detecting IR light) as high/on
          
  digitalWrite(TTL5, HIGH);   //This turns on TTL5. We do not change it in the rest of the code so that we can use this to power the IR light and sensor
  digitalWrite(TTL6, LOW);    //The intial state of the laser is off
  digitalWrite(TTL7, LOW);    //The intial state of the laser is off
  digitalWrite(TTL8, HIGH);    //The intial state of the reward is closed (high)
}

//This is the code that the Arduino loops through. It reads each sensor in series. If a sensor changes state (the beam is broken), it then outputs TTLs. 
void loop() 
{
  
  ///////////////////////////Read the IR sensor1
  sensorState1 = digitalRead (TTL1);

  //Check to see if the beam is broken.
  if (sensorState1 == LOW) 
  {
    //If sensor1 (Arm1) is broken (LOW), 
    for (int i = 0; i < ChR2numrepeat; i++) 
    {
      //Condition 1
      digitalWrite(TTL6, HIGH);
      delay(ChR2con1);

      //Condition 2
      digitalWrite(TTL6, LOW);
      delay(ChR2con2);

      //This states that when the optogenetic stimulation loop is completed, then set the read pin back to high, just as was done in the initialization.
      //You need not worry too much about this, but if you would like more information, SparkFun has a pretty good tutorial on 'floating' and 'pull up resistors'
      if (i == ChR2numrepeat - 1) 
      {
      digitalWrite(TTL1, HIGH);
      }
    }
  }
  
  //Without this section, optogenetic stimulation would be provided if the beam was continuously broken. We want only one stimulation pattern for a given nose poke.
  //Reread the IR sensor. We want to check that the mouse has left the nose poke before we deliver another stimulation.
  while (sensorState1 == LOW) 
  {
    delay(500);
    sensorState1 = digitalRead (TTL1);
  }

 
  ///////////////////////////Read the IR sensor2
  sensorState2 = digitalRead (TTL2);

  //Check to see if the beam is broken.
  if (sensorState2 == LOW) 
  {
    //If sensor2 (Arm2) is broken (LOW), 
    for (int i = 0; i < Jawsnumrepeat; i++) 
    {
      //Condition 1
      digitalWrite(TTL7, HIGH);
      delay(Jawscon1);

      //Condition 2
      digitalWrite(TTL7, LOW);
      delay(Jawscon2);

      //This states that when the optogenetic stimulation loop is completed, then set the read pin back to high, just as was done in the initialization.
      //You need not worry too much about this, but if you would like more information, SparkFun has a pretty good tutorial on 'floating' and 'pull up resistors'
      if (i == Jawsnumrepeat - 1) 
      {
      digitalWrite(TTL2, HIGH);
      }
    }
  }
  
  //Without this section, optogenetic stimulation would be provided if the beam was continuously broken. We want only one stimulation pattern for a given nose poke.
  //Reread the IR sensor. We want to check that the mouse has left the nose poke before we deliver another stimulation.
  while (sensorState2 == LOW) 
  {
    delay(500);
    sensorState2 = digitalRead (TTL2);
  }

  ///////////////////////////Read the IR sensor3
  sensorState3 = digitalRead (TTL3);

  //Check to see if the beam is broken.
  if (sensorState3 == LOW) 
  {
    //If sensor3 (Arm3) is broken (LOW), 
    for (int i = 0; i < ChR2numrepeat; i++) 
    {
      //Condition 1
      digitalWrite(TTL6, HIGH);
      delay(ChR2con1);

      //Condition 2
      digitalWrite(TTL6, LOW);
      delay(ChR2con2);

      //This states that when the optogenetic stimulation loop is completed, then set the read pin back to high, just as was done in the initialization.
      //You need not worry too much about this, but if you would like more information, SparkFun has a pretty good tutorial on 'floating' and 'pull up resistors'
      if (i == ChR2numrepeat - 1) 
      {
      digitalWrite(TTL3, HIGH);
      }
    }
  }
  
  //Without this section, optogenetic stimulation would be provided if the beam was continuously broken. We want only one stimulation pattern for a given nose poke.
  //Reread the IR sensor. We want to check that the mouse has left the nose poke before we deliver another stimulation.
  while (sensorState3 == LOW) 
  {
    delay(500);
    sensorState3 = digitalRead (TTL3);
  }


///////////////////////////Read the IR sensor4
  sensorState4 = digitalRead (TTL4);

  //Check to see if the beam is broken.
  if (sensorState4 == LOW) 
  {
    //If sensor4 (Arm4) is broken (LOW), 
    for (int i = 0; i < Rewardnumrepeat; i++) 
    {
      //Condition 1
      digitalWrite(TTL8, LOW);
      delay(Rewardcon1);

      //This states that when the reward loop is completed, then set the read pin back to high, just as was done in the initialization.
      //You need not worry too much about this, but if you would like more information, SparkFun has a pretty good tutorial on 'floating' and 'pull up resistors'
      if (i == Rewardnumrepeat - 1) 
      {
      digitalWrite(TTL4, HIGH);
      digitalWrite(TTL8, HIGH);
      }
    }
  }
  
  //Without this section, reward would be provided if the beam was continuously broken. We want only one stimulation pattern for a given nose poke.
  //Reread the IR sensor. We want to check that the mouse has left the nose poke before we deliver another stimulation.
  while (sensorState4 == LOW) 
  {
    delay(500);
    sensorState4 = digitalRead (TTL4);
  }

}

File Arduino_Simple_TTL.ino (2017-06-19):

/*
 * Simple Arduino 4 Channel TTL Pulse Generator
 * Optogenetics and Neural Engineering Core ONE Core
 * University of Colorado
 * 10/5/16
 * See optogenetic.ucdenver.edu for more information, including a detailed write up and Arduino/BNC housing 3D Model
 * 
 * In this example, (4) unique TTL signals are sent out from the Arduino. Any time one signal changes, the condition of the Arduino changes.
 * The duration of each condition is set as well as the state of each channel.
 */

//This section defines the pins on the Arduino. We specify the intigers (int) TTL1 through TTL4.
//If you expanding this to require 6 channels, uncomment the last two lines here and add additional code below where needed.
int TTL1 = 2;
int TTL2 = 4;
int TTL3 = 7;
int TTL4 = 8;
//int TTL5 = 12;
//int TTL6 = 13; //Though, not recommend, as there are slight differences in this pin. If you must use pin 13 as a digital input, set its pinMode() to INPUT and use an external pull down resistor.

//This tells the Arduino to treat the pins as output. In this example, all channels are output. For an example with input (closed loop), see the Arduino-Simple_Closed_Loop.ino file section.
void setup() {
pinMode(TTL1, OUTPUT);
pinMode(TTL2, OUTPUT);
pinMode(TTL3, OUTPUT);
pinMode(TTL4, OUTPUT);
}

//Draw out the desired waves for each channel on paper, on the same timeline, such that channel 1 appears over channel 2, etc. The condition (or state) of the Arduino changes any time any of the channels change. See the write up for more information.
//Define the number of conditions. Define the length of time (in ms) for each condition. 
int con1 = 25;
int con2 = 25;
int con3 = 25;
int con4 = 25;
int con5 = 0;  //May be tempting to do, but it is recommended that the end of a pulse train NOT be considered as a condition.

//This is the code that the Arduino loops through. It will start on condition 1 and then move through the rest of the conditions and then auto restart back at condition 1.
//It writes each pin as High/ON or Low/Off for each condition, and the waits for the duration of condition (set above). 
void loop() {
    //Condition 1
  digitalWrite(TTL1,HIGH);
  digitalWrite(TTL2,HIGH);
  digitalWrite(TTL3,HIGH);
  digitalWrite(TTL4,LOW);
  delay(con1);
  
    //Condition 2
  digitalWrite(TTL1,HIGH);
  digitalWrite(TTL2,LOW);
  digitalWrite(TTL3,HIGH);
  digitalWrite(TTL4,LOW);
  delay(con2);

    //Condition 3
  digitalWrite(TTL1,LOW);
  digitalWrite(TTL2,HIGH);
  digitalWrite(TTL3,LOW);
  digitalWrite(TTL4,LOW);
  delay(con3);

    //Condition 4
  digitalWrite(TTL1,LOW);
  digitalWrite(TTL2,LOW);
  digitalWrite(TTL3,HIGH);
  digitalWrite(TTL4,LOW);
  delay(con4);

    //Condition 5    //May be tempting to do, but it is recommended that the end of a pulse train NOT be considered as a condition. Doing this may present problems as outlined in the write up (Channel 3).
  digitalWrite(TTL1,LOW);
  digitalWrite(TTL2,LOW);
  digitalWrite(TTL3,LOW);
  digitalWrite(TTL4,LOW);
  delay(con5);  
}
